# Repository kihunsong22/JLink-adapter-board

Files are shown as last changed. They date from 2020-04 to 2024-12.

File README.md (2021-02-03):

# JLink-adapter-board
JLink adapter board with most used connectors

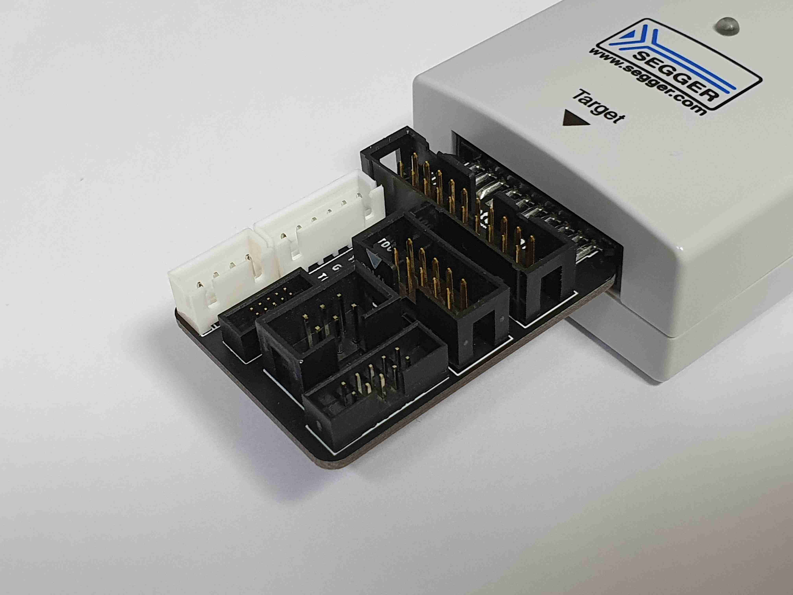
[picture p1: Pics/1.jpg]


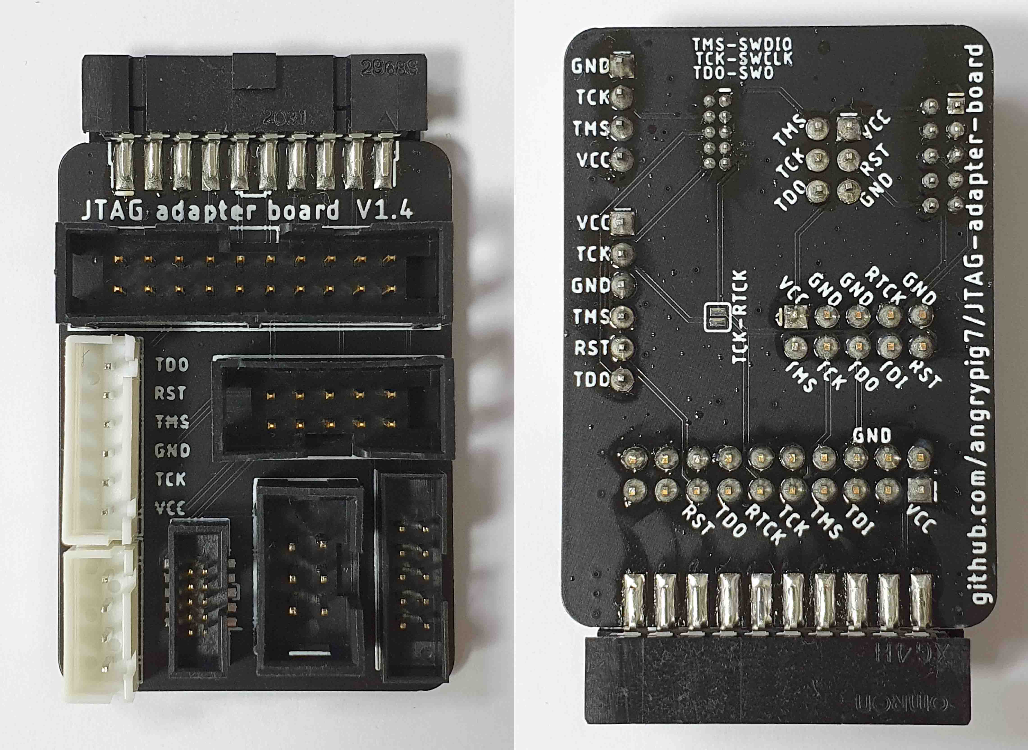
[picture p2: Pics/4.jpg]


### List of Connectors
* 2.54mm 2*10 pin female socket connector (for connecting to J-Link)
* 2.54mm 2*10 pin IDC male header connector
* 2.54mm 2*5 pin IDC male header connector
* 2.00mm 2*5 pin IDC male header connector
* 1.27mm 2*5 pin IDC male header connector (supports both SMD and PTH)
* 2.54mm 2*3 pin IDC male header connector - for Tag-Connect cable: [TC2030-IDC-NL](https://www.tag-connect.com/product/tc2030-idc-nl)
* 2.54mm 4 pin XH2.54 connector
* 2.54mm 6 pin XH2.54 connector

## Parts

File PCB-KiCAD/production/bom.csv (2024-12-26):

Designator | Footprint | Quantity | Value | LCSC Part #
C3 | 0805 | 1 | 22uF 25V | C45783
C4 | 0402 | 1 | 1uF | C52923
D1 | 0603 | 1 | LED, YELLOW | C72038
J1 | 2X10-2.54MM-END-LAUNCH | 1 | Conn_02x10_Odd_Even
J2 | PinHeader_2x07_P1.27mm_Vertical | 1 | Conn_02x07_IDC_1.27mm | C2935955
J3 | IDC-Header_2x03_P2.54mm_Vertical | 1 | Conn_02x03_IDC_2.54mm | C5372863
J4 | IDC-Header_2x05_P2.54mm_Vertical | 1 | Conn_02x05_IDC_2.54mm | C5665
J5 | PinHeader_2x05_P1.27mm_Vertical | 1 | Conn_02x05_IDC_1.27mm | C2962228
J6, J7 | JST_XH_B4B-XH-A_1x04_P2.50mm_Vertical | 2 | Conn_01x04 | C37815
J8 | USB_C_Receptacle_HRO_TYPE-C-31-M-17 | 1 | USB_C_Receptacle_PowerOnly_6P | C283541
R1, R2, R3 | 0402 | 3 | 5.1k | C25905
SW1 | SW_Push_1P1T_XKB_TS-1187A | 1 | SW_SPST | C318884
SW2 | DPDT-AYZ0202 | 1 | SW_DPDT_x2 | C318998
U1 | SOT-89-3 | 1 | AMS1117-3.3 | C5120796

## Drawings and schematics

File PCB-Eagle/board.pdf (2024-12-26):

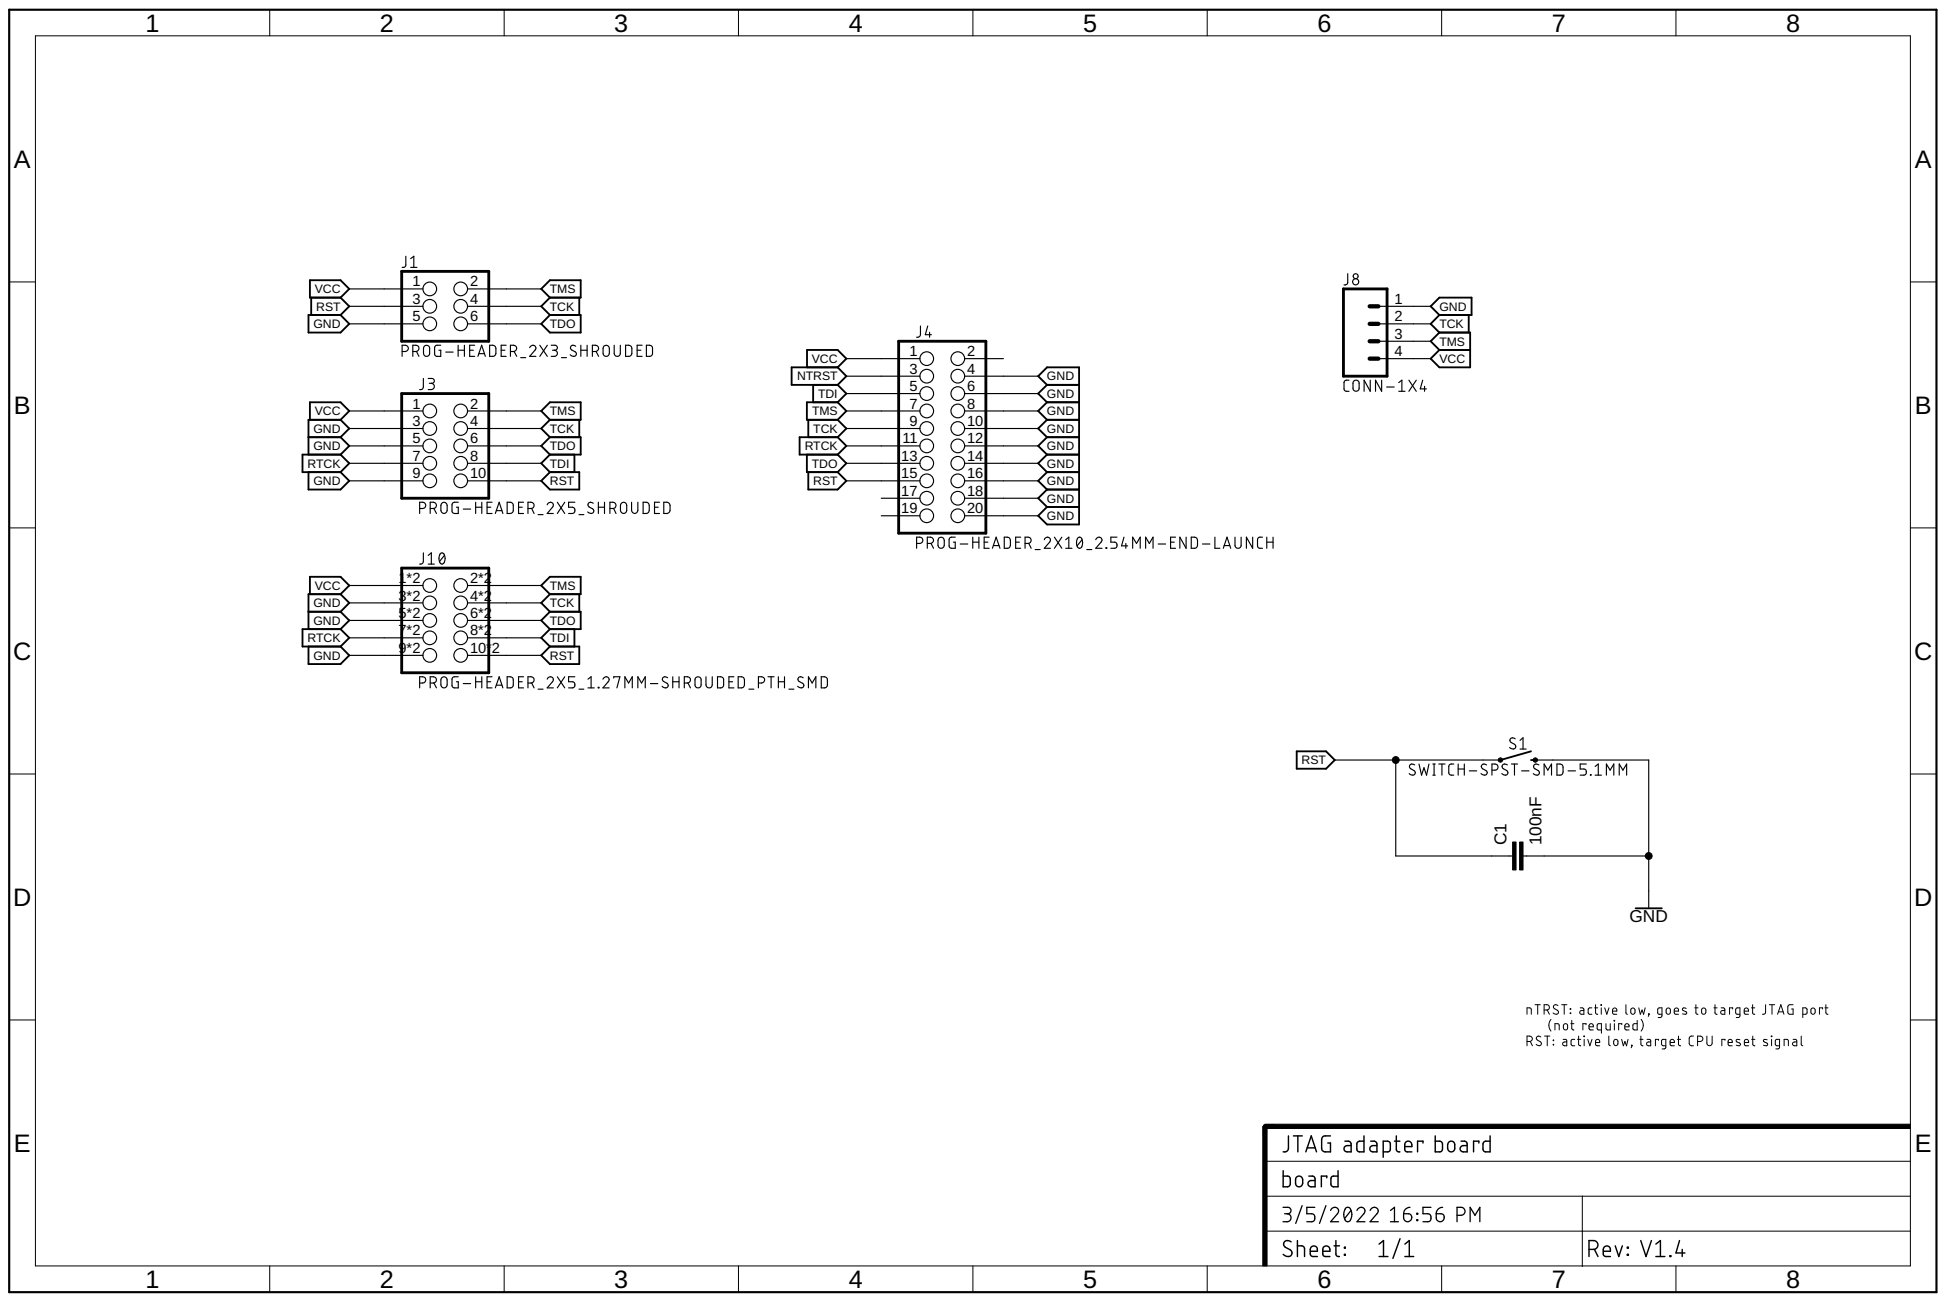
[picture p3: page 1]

100nF GND 1 2 3 4 5 6 1 24 5 6 7 8 9 10 3 1234 1*2 2*2 4*2 5*2 6*2 7*2 8*2 9*2 10*2 3*2 1 24 5 6 7 8 9 10 311 12 13 14 15 16 17 18 19 20 C1 VCC VCC VCC VCC VCC TMS TMS TMS TMS TMS TDO TDO TDO TDI TDO TDI TDI RST RST RST RST RST GND GND GND GND GND GND GND GND GND GND GND GND GND GND GND GND GND RTCK RTCK RTCK TCK TCK TCK TCK TCK NTRST ABCDE 1 2 3 4 5 6 7 8 ABCDE 1 2 3 4 5 6 7 8

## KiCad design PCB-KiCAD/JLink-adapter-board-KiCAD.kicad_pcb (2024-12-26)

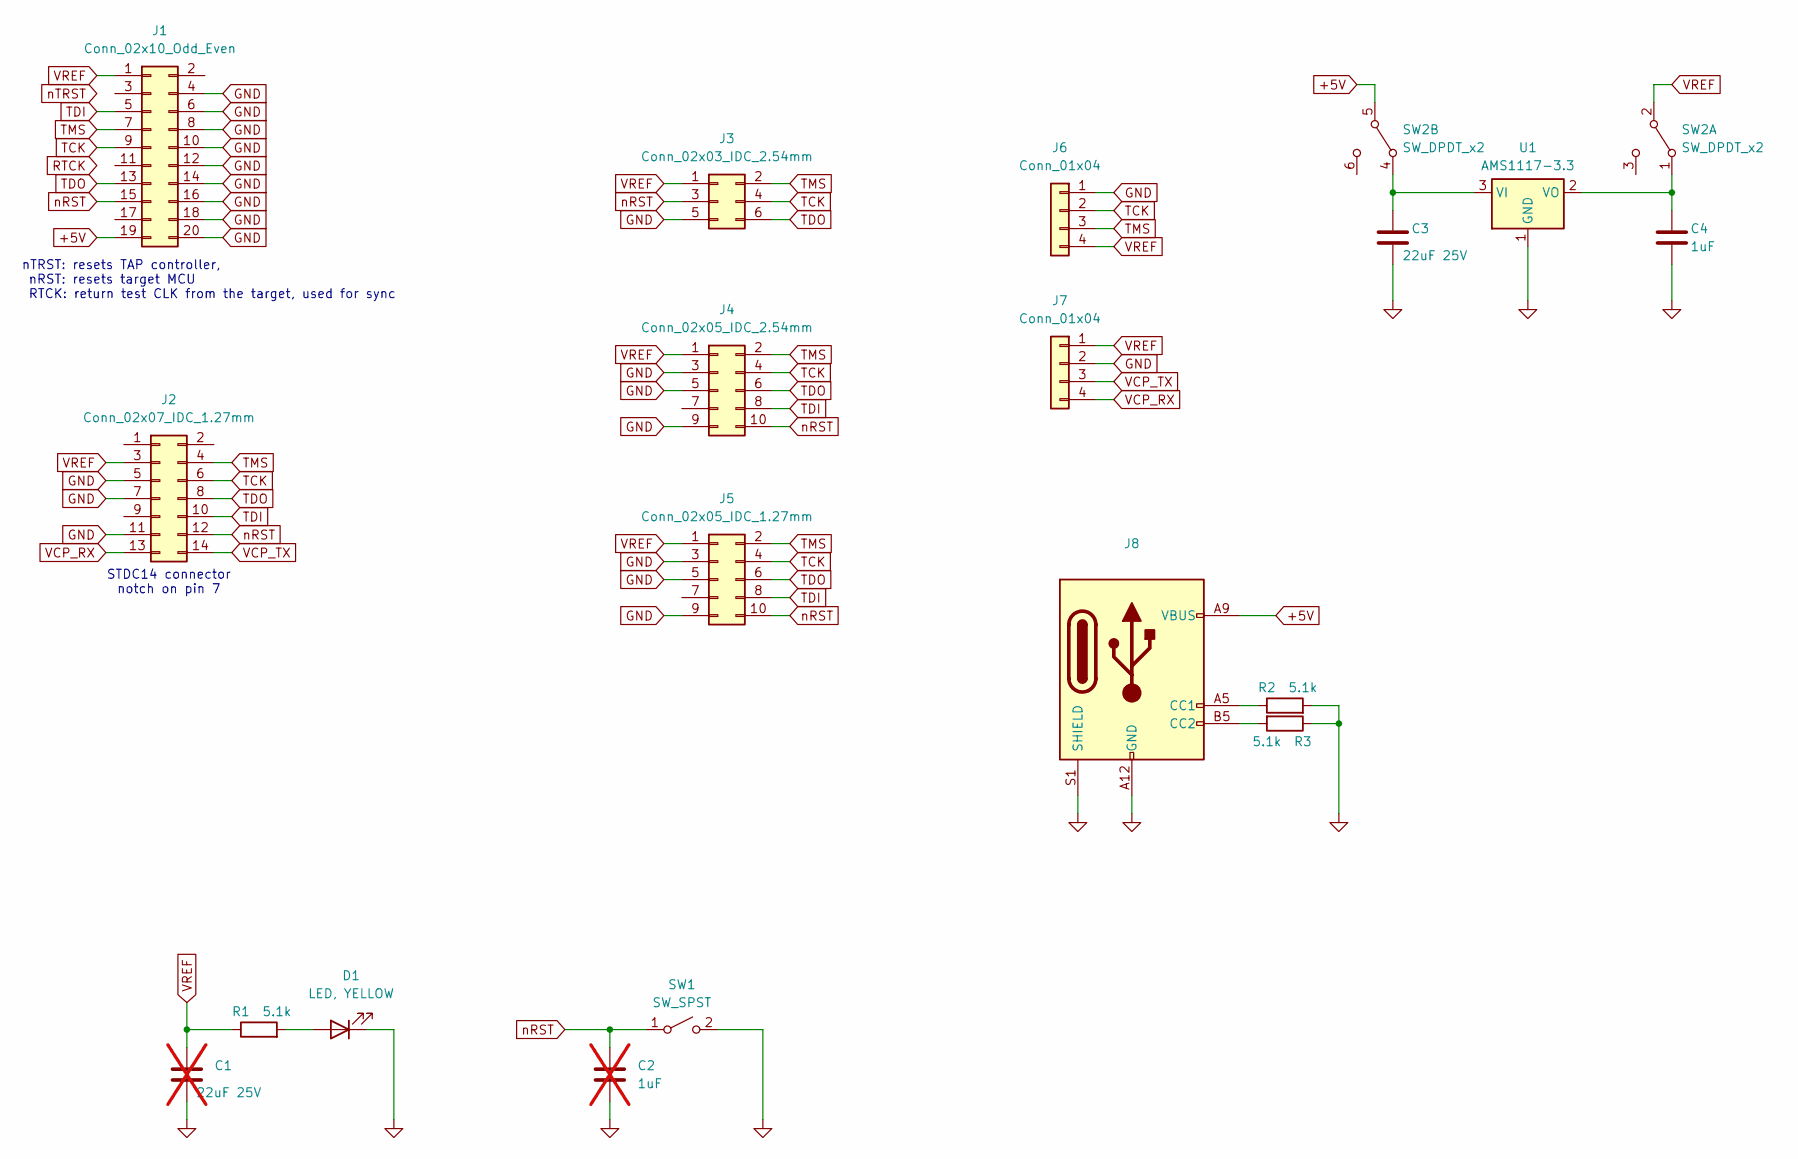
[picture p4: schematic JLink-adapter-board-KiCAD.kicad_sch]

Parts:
C1: 22uF 25V; C_0805_2012Metric; LCSC C45783; not fitted
C2: 1uF; C_0402_1005Metric; LCSC C52923; not fitted
C3: 22uF 25V; C_0805_2012Metric; LCSC C45783
C4: 1uF; C_0402_1005Metric; LCSC C52923
D1: LED, YELLOW; LED_0603_1608Metric; LCSC C72038
J1: Conn_02x10_Odd_Even; 2X10-2.54MM-END-LAUNCH; LCSC-notab C92266
J2: Conn_02x07_IDC_1.27mm; PinHeader_2x07_P1.27mm_Vertical; LCSC C2935955
J3: Conn_02x03_IDC_2.54mm; IDC-Header_2x03_P2.54mm_Vertical; LCSC C5372863
J4: Conn_02x05_IDC_2.54mm; IDC-Header_2x05_P2.54mm_Vertical; LCSC C5665
J5: Conn_02x05_IDC_1.27mm; PinHeader_2x05_P1.27mm_Vertical; LCSC C2962228
J6, J7: Conn_01x04; JST_XH_B4B-XH-A_1x04_P2.50mm_Vertical; LCSC C37815
J8: USB_C_Receptacle_PowerOnly_6P; USB_C_Receptacle_HRO_TYPE-C-31-M-17; LCSC C283541
R1, R2, R3: 5.1k; R_0402_1005Metric; LCSC C25905
SW1: SW_SPST; SW_Push_1P1T_XKB_TS-1187A; LCSC C318884
SW2: SW_DPDT_x2; DPDT-AYZ0202; LCSC C318998
U1: AMS1117-3.3; SOT-89-3; LCSC C5120796

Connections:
+5V: J1.19, J8.A9 (VBUS), J8.B9 (VBUS), SW2.5 (B)
GND: C1.2, C2.2, C3.2, C4.2, D1.1 (K), J1.4, J1.6, J1.8, J1.10, J1.12, J1.14, J1.16, J1.18, J1.20, J2.5, J2.7, J2.11, J3.5, J4.3, J4.5, J4.9, J5.3, J5.5, J5.9, J6.1, J7.2, J8.A12 (GND), J8.B12 (GND), J8.S1 (SHIELD), R2.2, R3.1, SW1.2 (B), U1.1 (GND)
unnamed: D1.2 (A), R1.2
unnamed: J8.A5 (CC1), R2.1
unnamed: J8.B5 (CC2), R3.2
unnamed: C4.1, SW2.1 (A), U1.2 (VO)
unnamed: C3.1, SW2.4 (A), U1.3 (VI)
TCK: J1.9, J2.6, J3.4, J4.4, J5.4, J6.2
TDI: J1.5, J2.10, J4.8, J5.8
TDO: J1.13, J2.8, J3.6, J4.6, J5.6
TMS: J1.7, J2.4, J3.2, J4.2, J5.2, J6.3
VCP_RX: J2.13, J7.4
VCP_TX: J2.14, J7.3
VREF: C1.1, J1.1, J2.3, J3.1, J4.1, J5.1, J6.4, J7.1, R1.1, SW2.2 (B)
nRST: C2.1, J1.15, J2.12, J3.3, J4.10, J5.10, SW1.1 (A)

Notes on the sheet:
nTRST: resets TAP controller, nRST: resets target MCU RTCK: return test CLK from the target, used for sync
STDC14 connector notch on pin 7

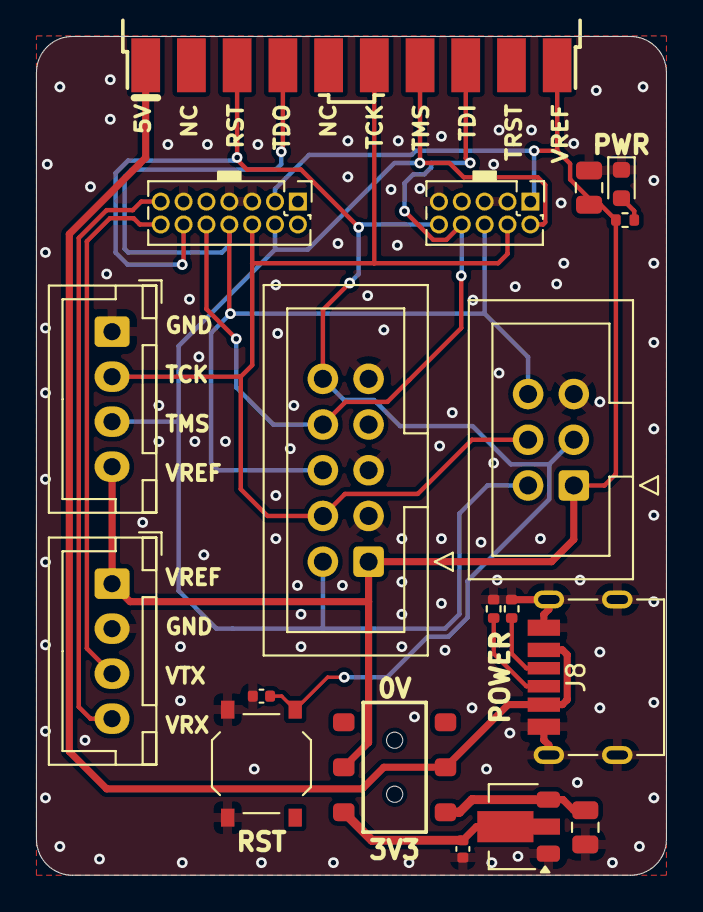
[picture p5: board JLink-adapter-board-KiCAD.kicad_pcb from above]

Board: 2 copper layers, 35.0 x 46.6 mm, 19 parts (0 on the bottom side), 15 nets.

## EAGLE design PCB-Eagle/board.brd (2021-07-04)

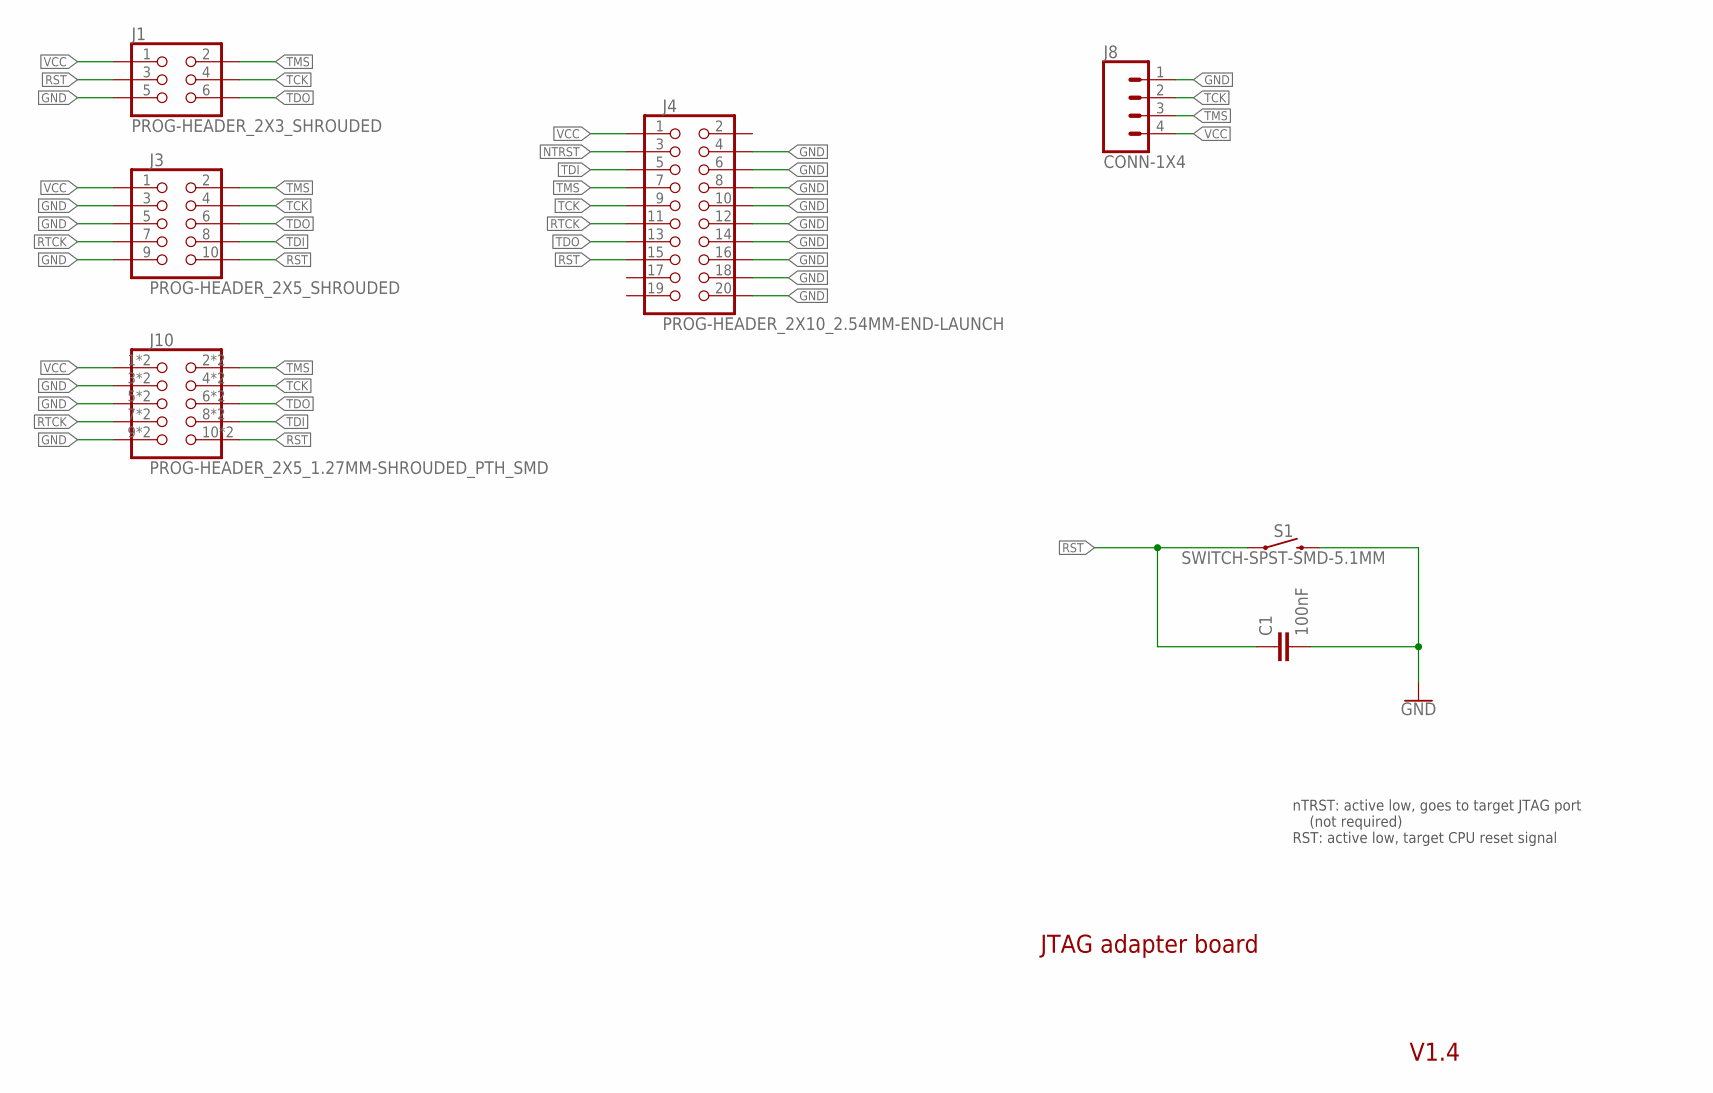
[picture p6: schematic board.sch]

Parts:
C1: 100nF; C0603
J1: PROG-HEADER_2X3_SHROUDED; 2X3-2.54MM-SHROUDED
J3: PROG-HEADER_2X5_SHROUDED; 2X5-2.54MM-SHROUDED
J4: PROG-HEADER_2X10_2.54MM-END-LAUNCH; 2X10-2.54MM-END-LAUNCH
J8: CONN-1X4; XH-4P-2.54MM
J10: PROG-HEADER_2X5_1.27MM-SHROUDED_PTH_SMD; 2X5-1.27MM-SHROUDED_PTH+SMD
S1: SWITCH-SPST-SMD-5.1MM; TACTILE_SWITCH_SMD_5.1MM

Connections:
2: J4.2
GND: C1.2, J1.5, J3.3, J3.5, J3.9, J4.4, J4.6, J4.8, J4.10, J4.12, J4.14, J4.16, J4.18, J4.20, J8.1, J10.3, J10.5, J10.9, J10.13 (3), J10.15 (5), J10.19 (9), S1.3 (2)
NTRST: J4.3
RST: C1.1, J1.3, J3.10, J4.15, J10.10, J10.20 (10), S1.1
RTCK: J3.7, J4.11, J10.7, J10.17 (7)
TCK: J1.4, J3.4, J4.9, J8.2, J10.4, J10.14 (4)
TDI: J3.8, J4.5, J10.8, J10.18 (8)
TDO: J1.6, J3.6, J4.13, J10.6, J10.16 (6)
TMS: J1.2, J3.2, J4.7, J8.3, J10.2, J10.12 (2)
VCC: J1.1, J3.1, J4.1, J8.4, J10.1, J10.11 (1)

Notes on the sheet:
nTRST: active low, goes to target JTAG port (not required) RST: active low, target CPU reset signal

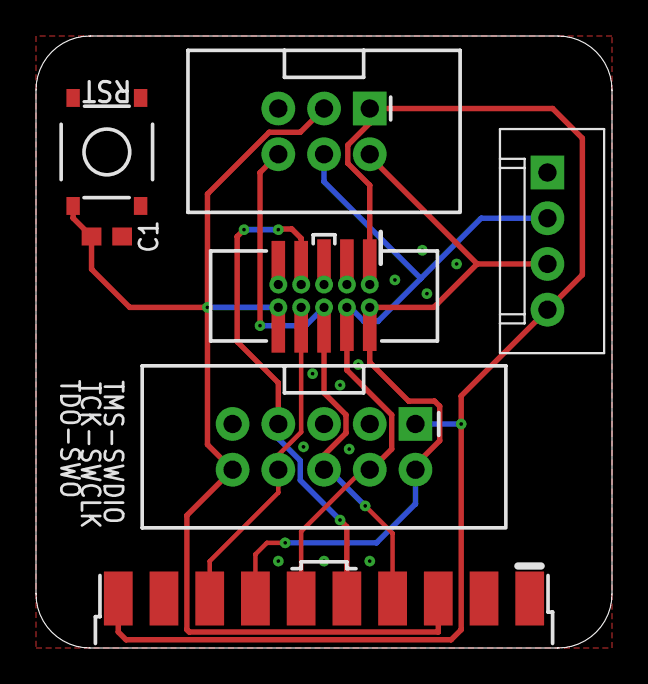
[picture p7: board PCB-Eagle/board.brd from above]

Board: 2 copper layers, 32.0 x 34.0 mm, 7 parts (0 on the bottom side), 8 nets.

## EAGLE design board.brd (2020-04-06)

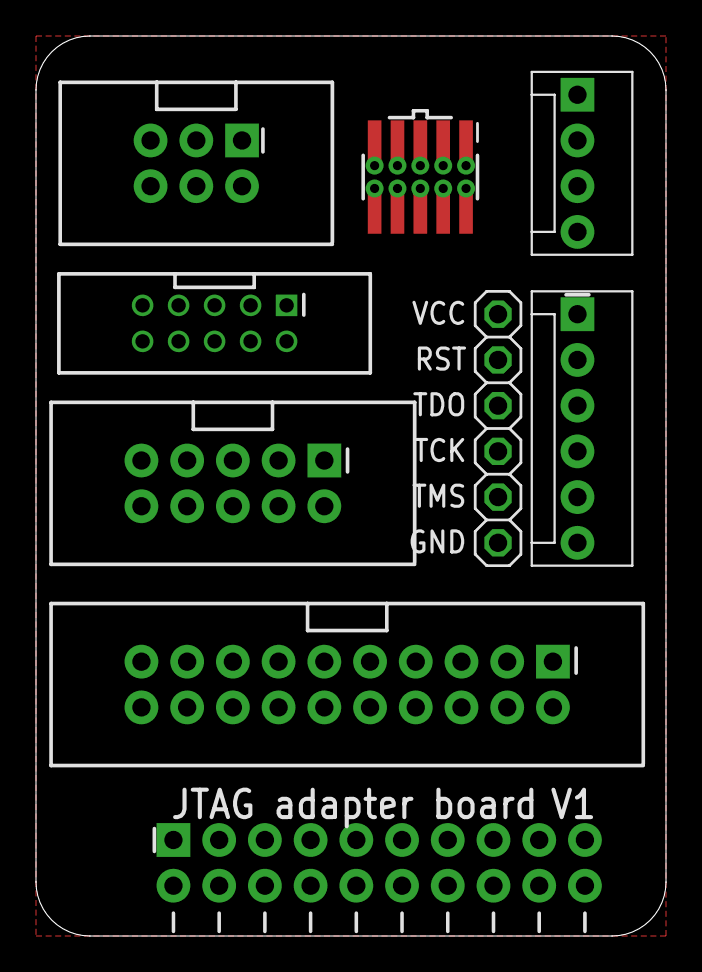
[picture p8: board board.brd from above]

Board: 2 copper layers, 35.0 x 50.0 mm, 10 parts (1 on the bottom side), 10 nets, no tracks yet.

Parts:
J1: PROG-HEADER_2X3_SHROUDED; 2X3-2.54MM-SHROUDED
J2: PROG-HEADER_2X5_2.00MM-SHROUDED; 2X5-2.00MM-SHROUDED
J3: PROG-HEADER_2X5_SHROUDED; 2X5-2.54MM-SHROUDED
J5: PROG-HEADER_2X10_RIGHT-ANGLE; 2X10-2.54MM-RIGHT-ANGLE
J6: PROG-HEADER_2X10_SHROUDED; 2X10-2.54MM-SHROUDED
J8: CONN-1X4; MOLEX-1X4-2.54MM
J9: CONN-1X6; MOLEX-1X6-2.54MM
J10: PROG-HEADER_2X5_1.27MM-PTH+SMD; 2X5-1.27MM_PTH+SMD
JP1: TCK-RTCK; SMT-JUMPER_2_NO_SILK
JP2: 1X06/OCT

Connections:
2: J5.2, J6.2
GND: J1.5, J2.3, J3.3, J5.4, J5.6, J5.8, J5.10, J5.12, J5.14, J5.16, J5.18, J5.20, J6.4, J6.6, J6.8, J6.10, J6.12, J6.14, J6.16, J6.18, J6.20, J8.1, J9.3, J10.3, J10.13, JP2.3
NTRST: J5.3, J6.3
RST: J1.3, J2.10, J3.10, J5.15, J6.15, J9.5, J10.10, J10.20, JP2.5
RTCK: J2.7, J3.7, J5.11, J6.11, J10.7, J10.17, JP1.2
TCK: J1.4, J2.4, J3.4, J5.9, J6.9, J8.2, J9.2, J10.4, J10.14, JP1.1, JP2.2
TDI: J2.8, J3.8, J5.5, J6.5, J10.8, J10.18
TDO: J1.6, J2.6, J3.6, J5.13, J6.13, J9.6, J10.6, J10.16, JP2.6
TMS: J1.2, J2.2, J3.2, J5.7, J6.7, J8.3, J9.4, J10.2, J10.12, JP2.4
VCC: J1.1, J2.1, J3.1, J5.1, J6.1, J8.4, J9.1, J10.1, J10.11, JP2.1

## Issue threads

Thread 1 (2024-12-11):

power capacitor should be behind the switch

kihunsong22, 2024-12-11:
3v3 capacitor from the adapter messes with target board's power rail upon connection, resetting the board

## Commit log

2020-04-06 moved repo
    [board.brd, board.sch]
2020-04-13 fixed weird text angle
    [board.brd]
2020-04-22 changed font size
    [board.brd, board.sch]
2020-04-22 V1.3 - changed text orientation
    [board.brd]
2020-05-01 connected pin 5, 9 to GND
    [board.brd, board.sch]
2020-05-15 changed right angle connector to end launch
    [board.brd, board.sch]
2020-05-27 fixed footprint error
    [board.brd, board.sch]
2020-08-01 V1.5
    - changed RST to TDI for 3*2 pin connector
    - optimized routing
    [board.brd, board.sch]
2021-02-03 rollback to V1.4
    [board.brd, board.sch]
2021-07-04 V1.6 update
    [board.brd, board.sch]
2024-12-26 DNP'd capacitors to not reset target board, fixed connector part links
    [JLink-adapter-board-KiCAD.kicad_pcb, JLink-adapter-board-KiCAD.kicad_sch, board.brd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]
2025-07-16 update .gitignore with KiCAD options

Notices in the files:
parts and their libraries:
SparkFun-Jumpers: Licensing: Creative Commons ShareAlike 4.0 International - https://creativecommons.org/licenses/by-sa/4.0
